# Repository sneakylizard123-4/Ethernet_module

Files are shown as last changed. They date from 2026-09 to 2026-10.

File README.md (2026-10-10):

# W5500 Ethernet Module

A small SPI Ethernet breakout for the W5500.

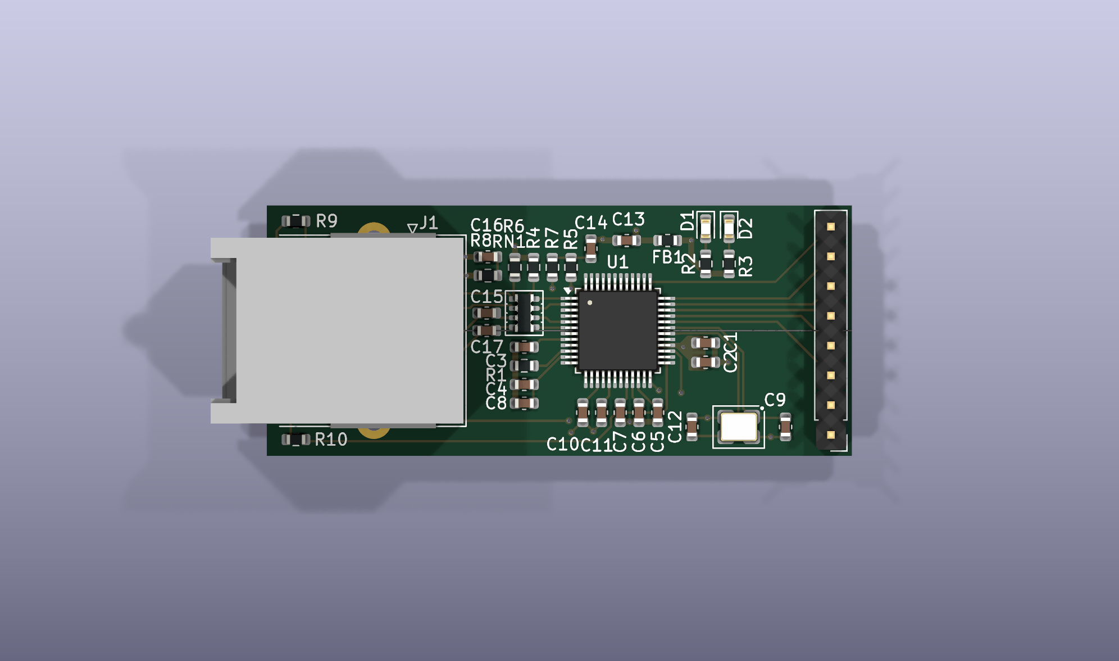
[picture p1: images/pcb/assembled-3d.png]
Assembled 3D render


## Features

- SPI interface
- 10/100 Ethernet
- 4-layer board with ground and 3.3V planes
- Split analog/digital supply with ferrite bead
- On-board and jack LEDs
- 25 MHz crystal

## PCB

50.0 x 21.4 mm, 4-layer, 1.6 mm FR-4.

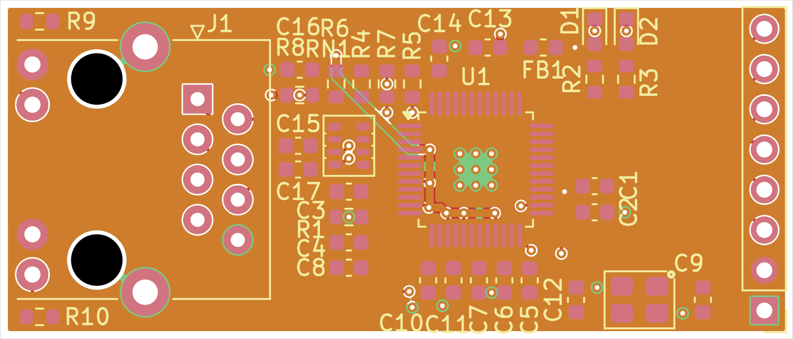
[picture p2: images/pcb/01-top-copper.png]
PCB top copper

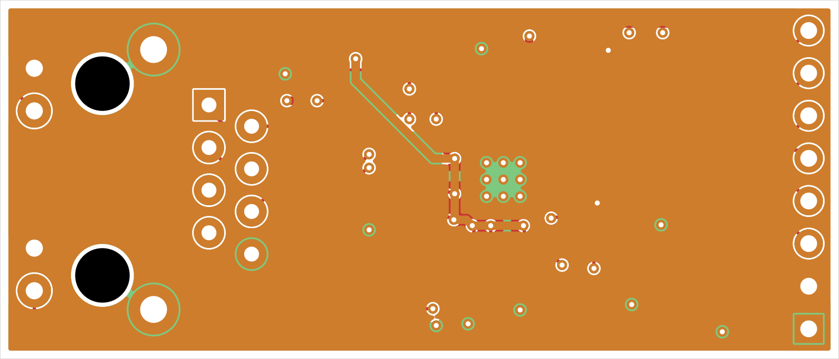
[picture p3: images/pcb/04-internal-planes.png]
Internal planes


## Schematic

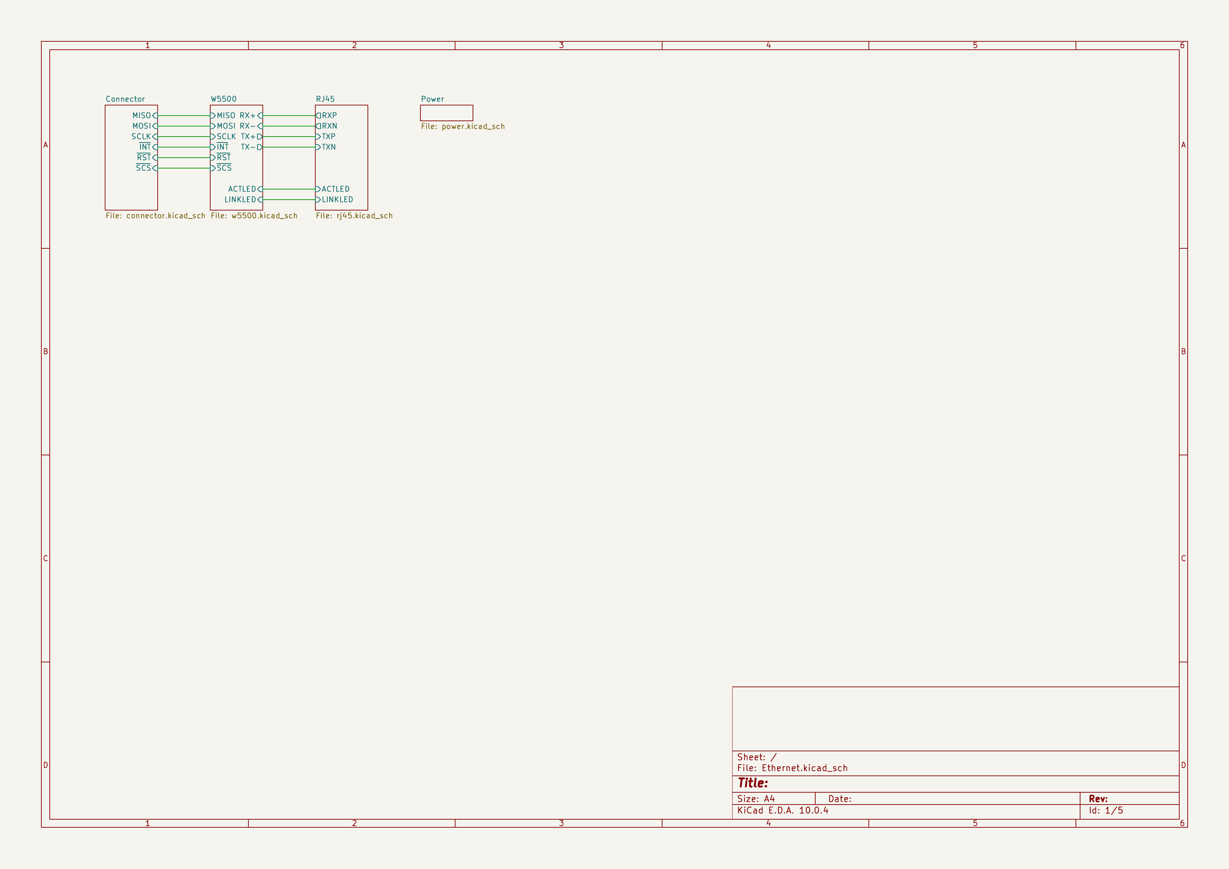
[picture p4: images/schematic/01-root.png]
Root

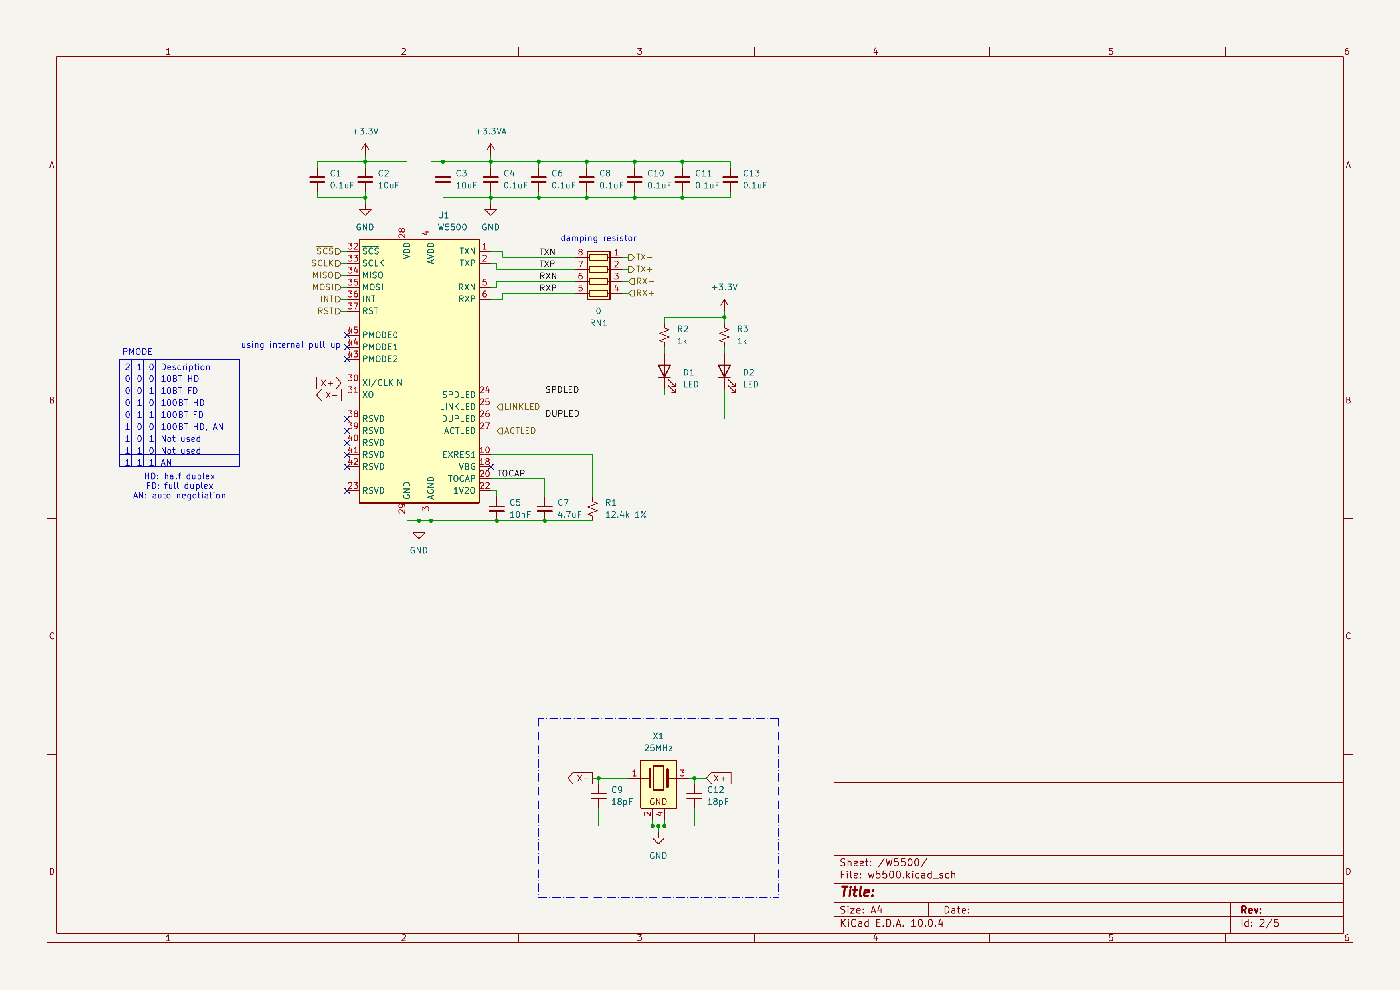
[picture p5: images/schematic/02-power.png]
Power

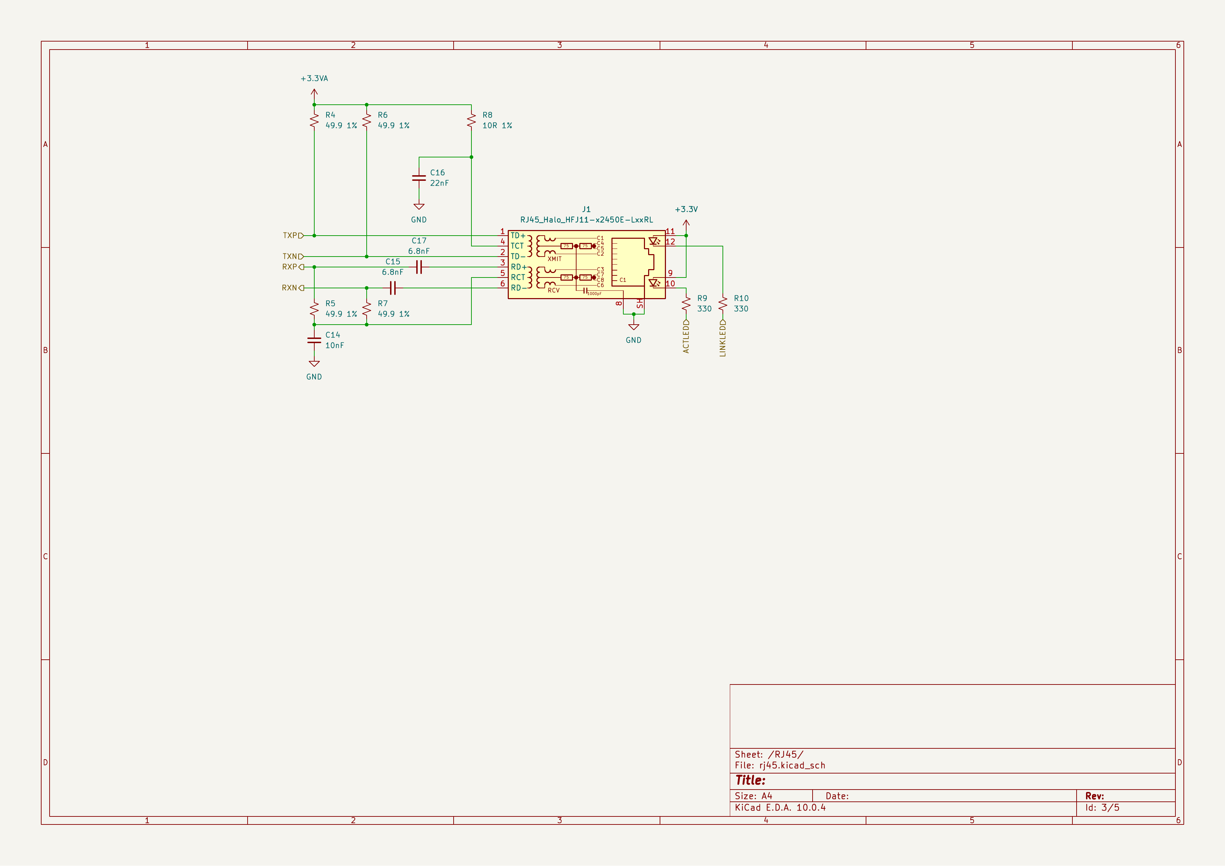
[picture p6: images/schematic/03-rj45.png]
RJ45

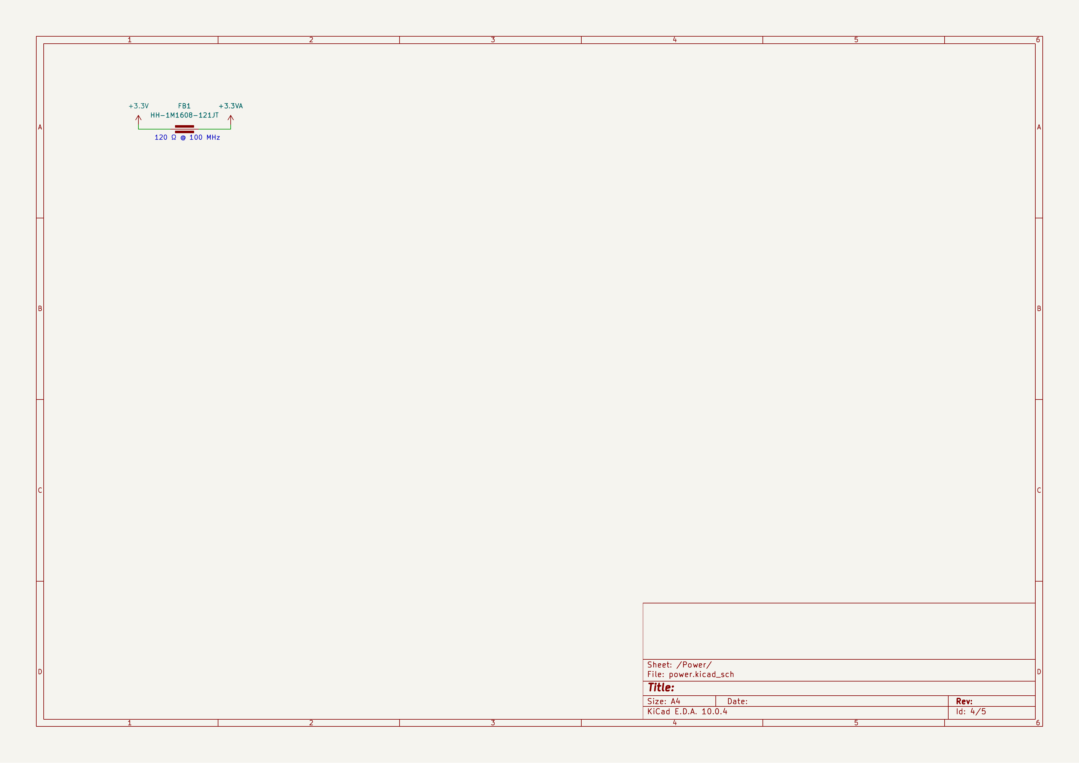
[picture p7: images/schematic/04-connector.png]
Connector

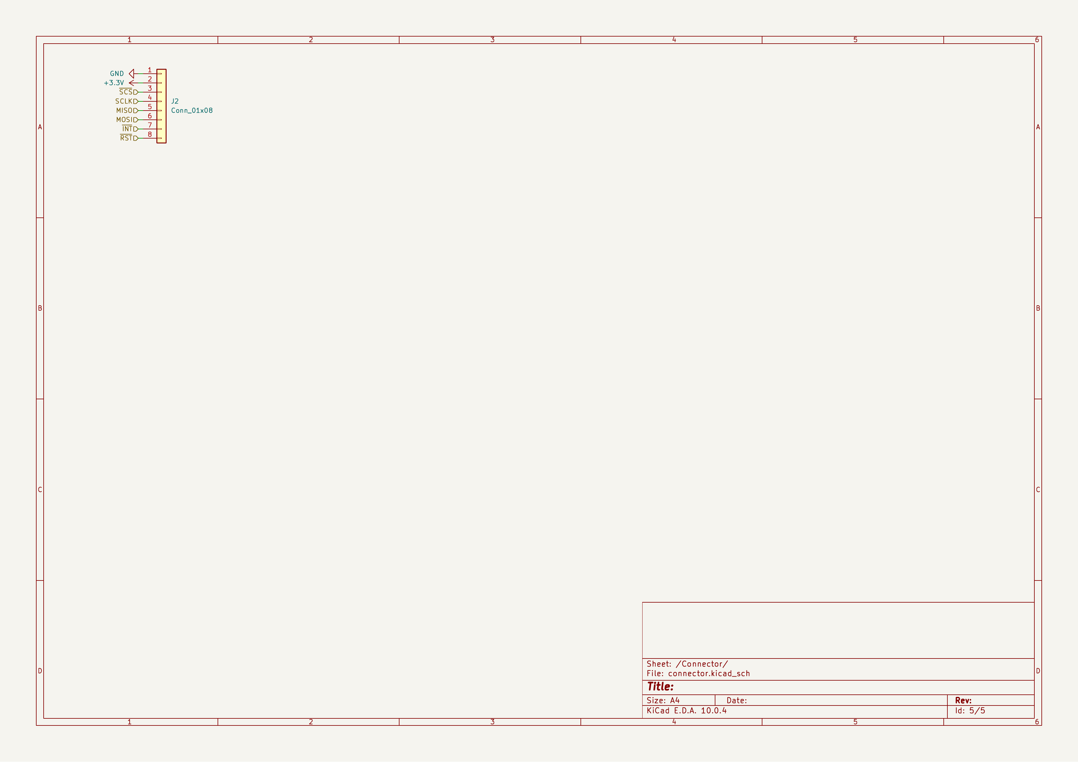
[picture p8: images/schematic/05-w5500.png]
W5500


## Pinout

| Pin | Name | Notes |
|---|---|---|
| 1 | GND | Ground |
| 2 | 3.3V | Power in |
| 3 | SCS | Chip select (active low) |
| 4 | SCLK | SPI clock |
| 5 | MISO | SPI MISO |
| 6 | MOSI | SPI MOSI |
| 7 | INT | Interrupt (active low) |
| 8 | RST | Reset (active low) |

## BOM

| Ref | Value | MPN | Manufacturer | Qty | Unit $ | Ext $ | Supplier Link |
|-----|---|-----|---|-----|---|---|---|
| C1,C4,C6,C8,C10,C11,C13 | 0.1uF 50V X7R 0603 | CL10B104KB8NNNC | Samsung Electro-Mechanics | 7 | 0.0088 | 0.0616 | [LCSC](https://www.lcsc.com/product-detail/Samsung-Electro-Mechanics-CL10B104KB8NNNC_C1591.html) |
| C9,C12 | 18pF 50V C0G 0603 | 0603N180J500CT | Union Semiconductor | 2 | 0.0069 | 0.0138 | [LCSC](https://www.lcsc.com/product-detail/Union-Semiconductor-0603N180J500CT_C123538.html) |
| C5,C14 | 10nF 50V X7R 0603 | CL10B103KB8NNNC | Samsung Electro-Mechanics | 2 | 0.0103 | 0.0206 | [LCSC](https://www.lcsc.com/product-detail/Samsung-Electro-Mechanics-CL10B103KB8NNNC_C1589.html) |
| C15,C17 | 6.8nF 50V X7R 0603 | CL10B682JB8NNNC | Samsung Electro-Mechanics | 2 | 0.0075 | 0.0150 | [LCSC](https://www.lcsc.com/product-detail/Samsung-Electro-Mechanics-CL10B682JB8NNNC_C307492.html) |
| C16 | 22nF 50V X7R 0603 | CC0603KRX7R9BB223 | Yageo | 1 | 0.0063 | 0.0063 | [LCSC](https://www.lcsc.com/product-detail/YAGEO-CC0603KRX7R9BB223_C106222.html) |
| C2,C3 | 10uF 10V X5R 0603 | CL10A106KP8NNNC | Samsung Electro-Mechanics | 2 | 0.0322 | 0.0644 | [LCSC](https://www.lcsc.com/product-detail/Samsung-Electro-Mechanics-CL10A106KP8NNNC_C19702.html) |
| C7 | 4.7uF 10V X5R 0603 | CL10A475KP8NNNC | Samsung Electro-Mechanics | 1 | 0.0164 | 0.0164 | [LCSC](https://www.lcsc.com/product-detail/Samsung-Electro-Mechanics-CL10A475KP8NNNC_C1705.html) |
| D1,D2 | LED red high-efficiency 0603 | KT-0603R | Keystone Electronics | 2 | 0.0076 | 0.0152 | [LCSC](https://www.lcsc.com/product-detail/Keystone-Electronics-KT-0603R_C2286.html) |
| FB1 | Ferrite bead 120R 0603 | CBW160808U121T | Sunlord | 1 | 0.0086 | 0.0086 | [LCSC](https://www.lcsc.com/product-detail/Sunlord-CBW160808U121T_C139175.html) |
| J1 | RJ45 magjack HFJ11-2450E-L11RL | HFJ11-2450E-L11RL | Halo Electronics | 1 | 5.2300 | 5.2300 | [DigiKey](https://www.digikey.com/en/products/detail/halo-electronics-inc/HFJ11-2450E-L11RL/25658121) |
| J2 | Header 1x08 2.54mm | 2.54-1*8 | CONNFLY Elec | 1 | 0.0442 | 0.0442 | [LCSC](https://www.lcsc.com/product-detail/CONNFLY-Elec-2-54-1-8_C5156616.html) |
| R1 | 12.4k 1% 0603 | 0603WAF1242T5E | UniRoyal Elec | 1 | 0.0015 | 0.0015 | [LCSC](https://www.lcsc.com/product-detail/UNI-ROYAL-Uniroyal-Elec-0603WAF1242T5E_C22865.html) |
| R2,R3 | 1k 1% 0603 | 0603WAF1001T5E | UniRoyal Elec | 2 | 0.0026 | 0.0052 | [LCSC](https://www.lcsc.com/product-detail/UNI-ROYAL-Uniroyal-Elec-0603WAF1001T5E_C21190.html) |
| R4,R5,R6,R7 | 49.9R 1% 0603 | RC0603FR-0749R9L | Yageo | 4 | 0.0062 | 0.0248 | [LCSC](https://www.lcsc.com/product-detail/YAGEO-RC0603FR-0749R9L_C114625.html) |
| R8 | 10R 1% 0603 | 0603WAF100JT5E | UniRoyal Elec | 1 | 0.0032 | 0.0032 | [LCSC](https://www.lcsc.com/product-detail/UNI-ROYAL-Uniroyal-Elec-0603WAF100JT5E_C22859.html) |
| R9,R10 | 330R 1% 0603 | 0603WAF3300T5E | UniRoyal Elec | 2 | 0.0026 | 0.0052 | [LCSC](https://www.lcsc.com/product-detail/UNI-ROYAL-Uniroyal-Elec-0603WAF3300T5E_C23138.html) |
| RN1 | 0R array 0603x4 | 4D03WGJ0000T5E | UniRoyal Elec | 1 | 0.0090 | 0.0090 | [LCSC](https://www.lcsc.com/product-detail/UNI-ROYAL-Uniroyal-Elec-4D03WGJ0000T5E_C1952.html) |
| U1 | W5500 LQFP-48 | W5500 | WIZnet | 1 | 2.8503 | 2.8503 | [LCSC](https://www.lcsc.com/product-detail/WIZnet-W5500_C32843.html) |
| X1 | 25MHz 3225 | TXC-7A-25.000MBB-T | TXC Corporation | 1 | 0.0954 | 0.0954 | [LCSC](https://www.lcsc.com/product-detail/TXC-Corp-TXC-7A-25-000MBB-T_C9006.html) |
| PCB | 50.0x21.4mm 4-layer FR-4 (5 pcs, est.) | - | JLCPCB | 5 | 2.0000 | 10.0000 | [JLCPCB](https://jlcpcb.com/) |
| **Total (parts per 1 board)** | | | | | | **8.49** | |
| **Grand total (5 boards: parts + PCBs)** | | | | | | **52.45** | |

Full BOM: [BOM.csv](BOM.csv)

## Production

Gerbers, drill files, STEP, IPC netlists, and placement files are in `kicad/production/`.

## Known issues

- The RJ45 mating face is ~6.1 mm closer to the board center than Halo recommends. Check case clearances.
- No mounting holes.

## License

Hardware: CERN-OHL-S-2.0. This covers the board design and the reconstructed 3D model for the magjack.

Based on WIZnet's W5500 reference design.

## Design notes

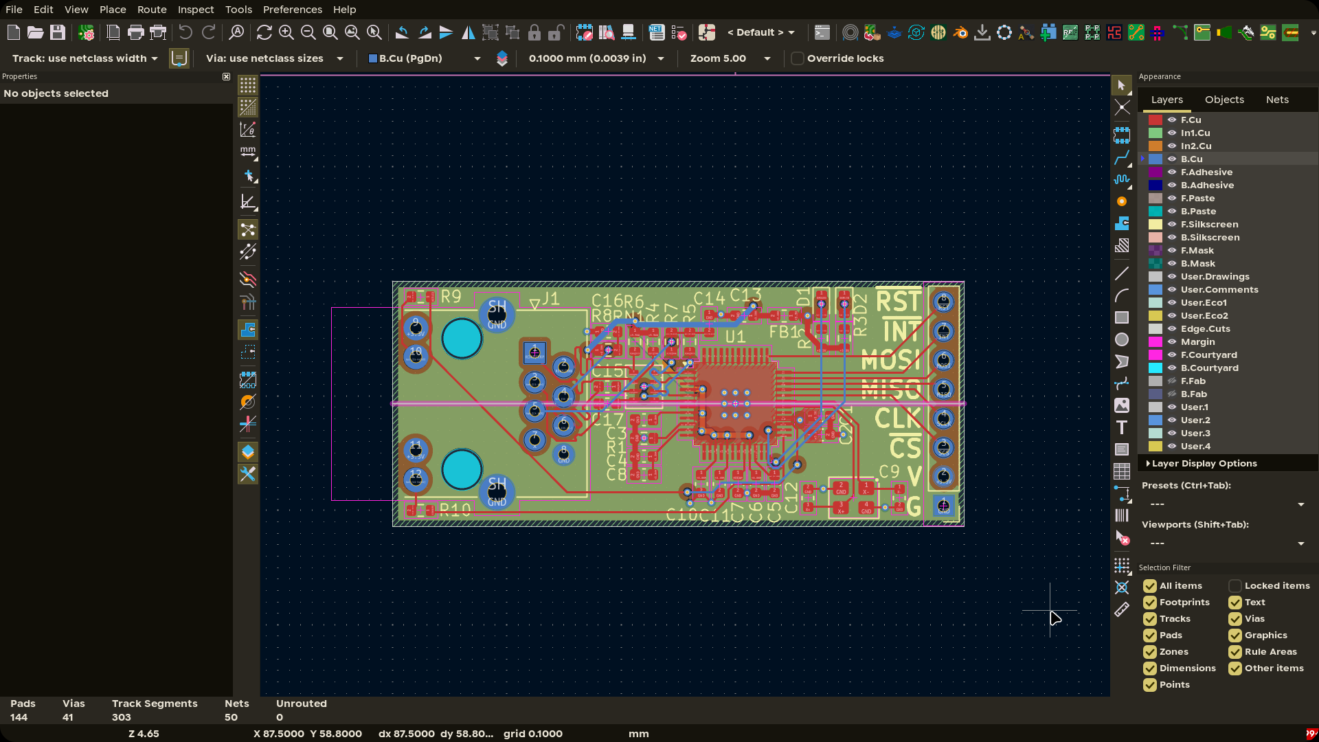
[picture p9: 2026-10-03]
images/pcb/image.png

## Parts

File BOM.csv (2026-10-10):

Designators | Value | Manufacturer Part Number | Manufacturer | Supplier | Supplier Link | Qty | Unit Price (USD) | Extended Price (USD)
C1,C4,C6,C8,C10,C11,C13 | 0.1uF 50V X7R 0603 | CL10B104KB8NNNC | Samsung Electro-Mechanics | LCSC | https://www.lcsc.com/product-detail/Samsung-Electro-Mechanics-CL10B104KB8NNNC_C1591.html | 7 | 0.0088 | 0.0616
C9,C12 | 18pF 50V C0G 0603 | 0603N180J500CT | Union Semiconductor | LCSC | https://www.lcsc.com/product-detail/Union-Semiconductor-0603N180J500CT_C123538.html | 2 | 0.0069 | 0.0138
C5,C14 | 10nF 50V X7R 0603 | CL10B103KB8NNNC | Samsung Electro-Mechanics | LCSC | https://www.lcsc.com/product-detail/Samsung-Electro-Mechanics-CL10B103KB8NNNC_C1589.html | 2 | 0.0103 | 0.0206
C15,C17 | 6.8nF 50V X7R 0603 | CL10B682JB8NNNC | Samsung Electro-Mechanics | LCSC | https://www.lcsc.com/product-detail/Samsung-Electro-Mechanics-CL10B682JB8NNNC_C307492.html | 2 | 0.0075 | 0.0150
C16 | 22nF 50V X7R 0603 | CC0603KRX7R9BB223 | Yageo | LCSC | https://www.lcsc.com/product-detail/YAGEO-CC0603KRX7R9BB223_C106222.html | 1 | 0.0063 | 0.0063
C2,C3 | 10uF 10V X5R 0603 | CL10A106KP8NNNC | Samsung Electro-Mechanics | LCSC | https://www.lcsc.com/product-detail/Samsung-Electro-Mechanics-CL10A106KP8NNNC_C19702.html | 2 | 0.0322 | 0.0644
C7 | 4.7uF 10V X5R 0603 | CL10A475KP8NNNC | Samsung Electro-Mechanics | LCSC | https://www.lcsc.com/product-detail/Samsung-Electro-Mechanics-CL10A475KP8NNNC_C1705.html | 1 | 0.0164 | 0.0164
D1,D2 | LED red high-efficiency 0603 | KT-0603R | Keystone Electronics | LCSC | https://www.lcsc.com/product-detail/Keystone-Electronics-KT-0603R_C2286.html | 2 | 0.0076 | 0.0152
FB1 | Ferrite bead 120R at 100MHz 0603 | CBW160808U121T | Sunlord | LCSC | https://www.lcsc.com/product-detail/Sunlord-CBW160808U121T_C139175.html | 1 | 0.0086 | 0.0086
J1 | RJ45 magjack 10/100 Base-T tab-down green/green LED | HFJ11-2450E-L11RL | Halo Electronics | DigiKey | https://www.digikey.com/en/products/detail/halo-electronics-inc/HFJ11-2450E-L11RL/25658121 | 1 | 5.2300 | 5.2300
J2 | Header 1x08 2.54mm vertical through-hole | 2.54-1*8 | CONNFLY Elec | LCSC | https://www.lcsc.com/product-detail/CONNFLY-Elec-2-54-1-8_C5156616.html | 1 | 0.0442 | 0.0442
R1 | 12.4k 1% 0603 | 0603WAF1242T5E | UniRoyal Elec | LCSC | https://www.lcsc.com/product-detail/UNI-ROYAL-Uniroyal-Elec-0603WAF1242T5E_C22865.html | 1 | 0.0015 | 0.0015
R2,R3 | 1k 1% 0603 | 0603WAF1001T5E | UniRoyal Elec | LCSC | https://www.lcsc.com/product-detail/UNI-ROYAL-Uniroyal-Elec-0603WAF1001T5E_C21190.html | 2 | 0.0026 | 0.0052
R4,R5,R6,R7 | 49.9R 1% 0603 | RC0603FR-0749R9L | Yageo | LCSC | https://www.lcsc.com/product-detail/YAGEO-RC0603FR-0749R9L_C114625.html | 4 | 0.0062 | 0.0248
R8 | 10R 1% 0603 | 0603WAF100JT5E | UniRoyal Elec | LCSC | https://www.lcsc.com/product-detail/UNI-ROYAL-Uniroyal-Elec-0603WAF100JT5E_C22859.html | 1 | 0.0032 | 0.0032
R9,R10 | 330R 1% 0603 | 0603WAF3300T5E | UniRoyal Elec | LCSC | https://www.lcsc.com/product-detail/UNI-ROYAL-Uniroyal-Elec-0603WAF3300T5E_C23138.html | 2 | 0.0026 | 0.0052
RN1 | 0R jumper array 4 elements 0603x4 convex | 4D03WGJ0000T5E | UniRoyal Elec | LCSC | https://www.lcsc.com/product-detail/UNI-ROYAL-Uniroyal-Elec-4D03WGJ0000T5E_C1952.html | 1 | 0.0090 | 0.0090
U1 | W5500 10/100 Ethernet SPI controller LQFP-48 7x7mm | W5500 | WIZnet | LCSC | https://www.lcsc.com/product-detail/WIZnet-W5500_C32843.html | 1 | 2.8503 | 2.8503
X1 | 25MHz crystal 12pF 3225-4P | TXC-7A-25.000MBB-T | TXC Corporation | LCSC | https://www.lcsc.com/product-detail/TXC-Corp-TXC-7A-25-000MBB-T_C9006.html | 1 | 0.0954 | 0.0954
PCB | 50.0mm x 21.4mm 4-layer FR-4 1.6mm HASL (5 pieces | estimated) | PCB | JLCPCB | JLCPCB | https://jlcpcb.com/ | 5 | 2.0000 | 10.0000
TOTAL per 1 board |  |  |  |  |  |  | 8.4907
TOTAL for 5 boards (parts only) |  |  |  |  |  |  | 42.4535
GRAND TOTAL (5 boards parts + 5 PCBs) |  |  |  |  |  |  | 52.4535

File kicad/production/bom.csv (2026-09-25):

Designator | Footprint | Quantity | Value | LCSC Part #
C1, C10, C11, C13, C4, C6, C8 | 0603 | 7 | 0.1uF
C12, C9 | 0603 | 2 | 18pF
C14, C5 | 0603 | 2 | 10nF
C15, C17 | 0603 | 2 | 6.8nF
C16 | 0603 | 1 | 22nF
C2, C3 | 0603 | 2 | 10uF
C7 | 0603 | 1 | 4.7uF
D1, D2 | 0603 | 2 | LED
FB1 | 0603 | 1 | HH-1M1608-121JT
J1 | RJ45_HALO_HFJ11-x2450E-LxxRL_Horizontal | 1 | RJ45_Halo_HFJ11-x2450E-LxxRL
J2 | PinHeader_1x08_P2.54mm_Vertical | 1 | Conn_01x08
R1 | 0603 | 1 | 12.4k 1%
R10, R9 | 0603 | 2 | 330
R2, R3 | 0603 | 2 | 1k
R4, R5, R6, R7 | 0603 | 4 | 49.9 1%
R8 | 0603 | 1 | 10R 1%
RN1 | R_Array_Convex_4x0603 | 1 | 0
U1 | LQFP-48_7x7mm_P0.5mm | 1 | W5500
X1 | Crystal_SMD_3225-4Pin_3.2x2.5mm | 1 | 25MHz

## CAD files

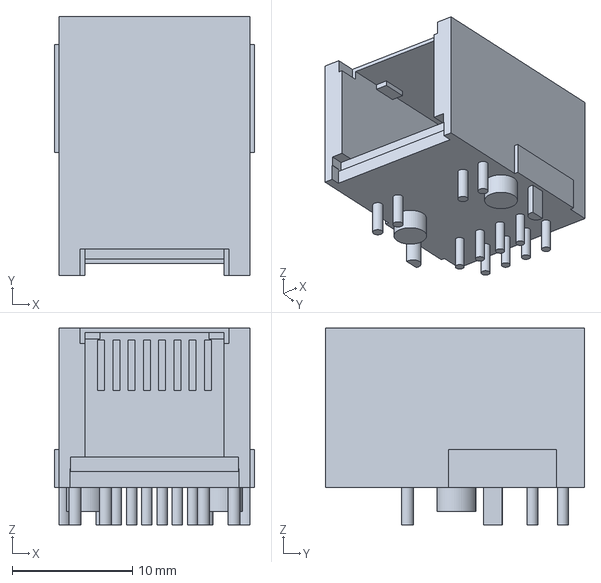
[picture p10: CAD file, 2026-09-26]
kicad/3dparts/halo_hfj11_x2450e_lxxrl.step
16.7 x 21.6 x 16.4 mm

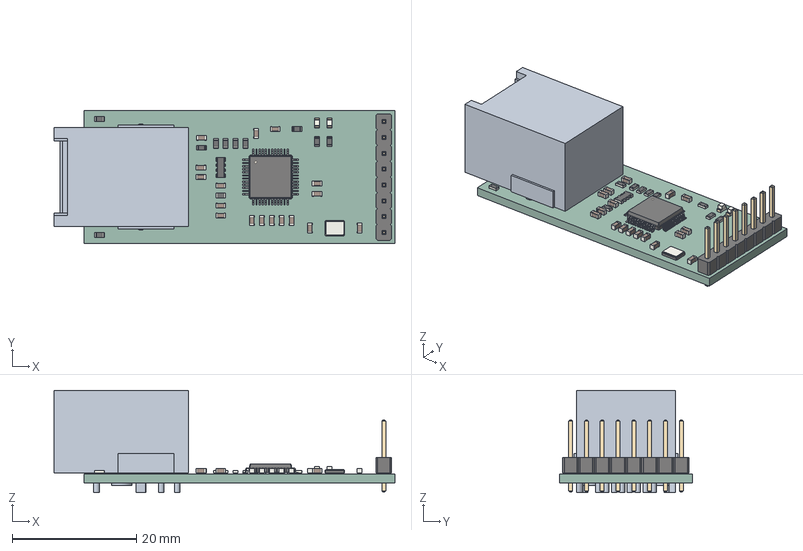
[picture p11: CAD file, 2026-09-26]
kicad/production/Ethernet.step
54.8 x 21.4 x 16.4 mm
C_0603_1608Metric x 17
R_0603_1608Metric x 10
R_Array_Convex_4x0603
LED_0603_1608Metric x 2
PinHeader_1x08_P254mm_Vertical
LQFP-48_7x7mm_P0.5mm
Fuse_0603_1608Metric
Crystal_SMD_3225-4Pin_3.2x2.5mm
Ethernet_PCB

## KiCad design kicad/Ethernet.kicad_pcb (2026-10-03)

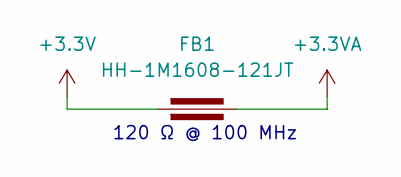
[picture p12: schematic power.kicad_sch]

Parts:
FB1: HH-1M1608-121JT; Fuse_0603_1608Metric

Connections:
+3.3V: FB1.1; also elsewhere on the board
+3.3VA: FB1.2; also elsewhere on the board

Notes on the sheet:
120 Ω @ 100 MHz

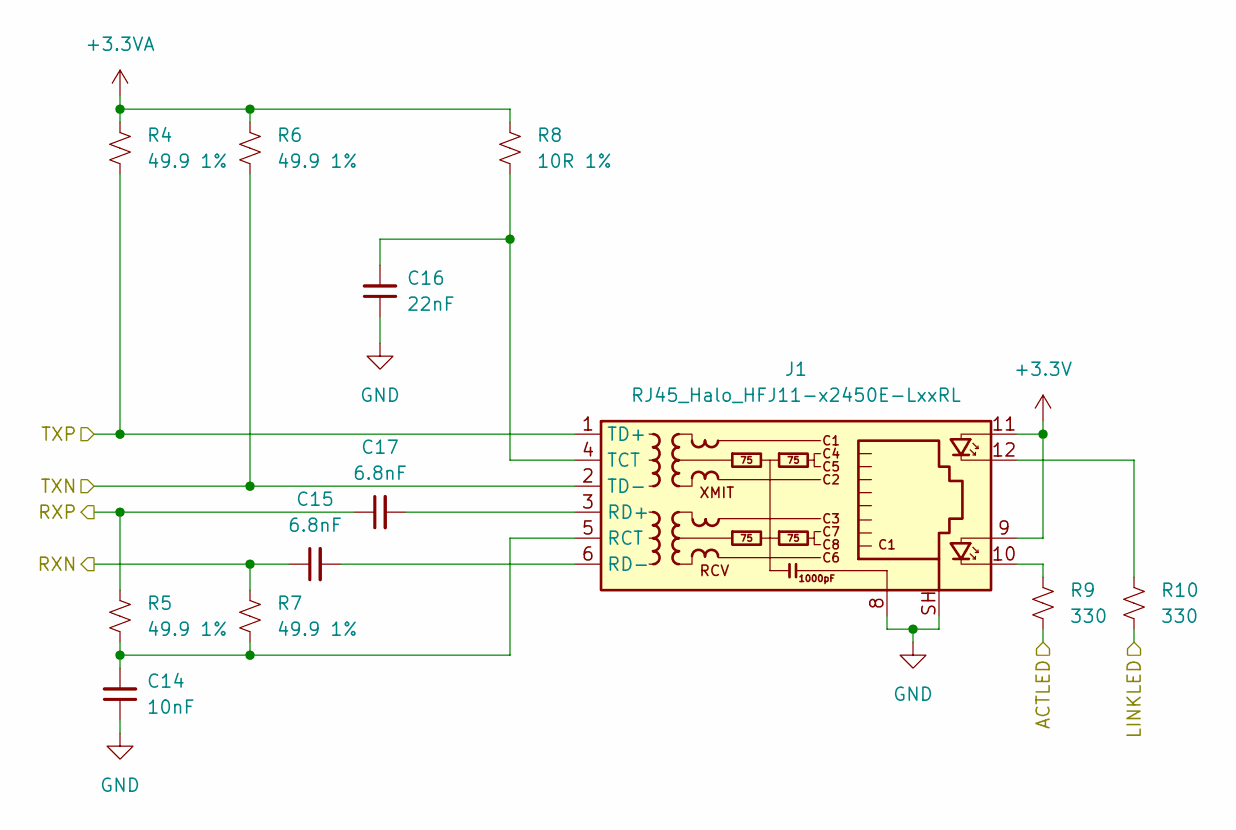
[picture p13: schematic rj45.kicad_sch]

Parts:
C14: 10nF; C_0603_1608Metric
C15, C17: 6.8nF; C_0603_1608Metric
C16: 22nF; C_0603_1608Metric
J1: RJ45_Halo_HFJ11-x2450E-LxxRL; RJ45_HALO_HFJ11-x2450E-LxxRL_Horizontal
R4, R5, R6, R7: 49.9 1%; R_0603_1608Metric
R8: 10R 1%; R_0603_1608Metric
R9, R10: 330; R_0603_1608Metric

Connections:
+3.3V: J1.9, J1.11; also elsewhere on the board
+3.3VA: R4.1, R6.1, R8.1; also elsewhere on the board
/RJ45/ACTLED: R9.1; also elsewhere on the board
/RJ45/LINKLED: R10.1; also elsewhere on the board
/RJ45/RXN: C15.1, R7.1; also elsewhere on the board
/RJ45/RXP: C17.1, R5.1; also elsewhere on the board
/RJ45/TXN: J1.2 (TD-), R6.2; also elsewhere on the board
/RJ45/TXP: J1.1 (TD+), R4.2; also elsewhere on the board
GND: C14.1, C16.1, J1.8, J1.SH; also elsewhere on the board
unnamed: J1.10, R9.2
unnamed: J1.12, R10.2
unnamed: C14.2, J1.5 (RCT), R5.2, R7.2
unnamed: C17.2, J1.3 (RD+)
unnamed: C15.2, J1.6 (RD-)
unnamed: C16.2, J1.4 (TCT), R8.2

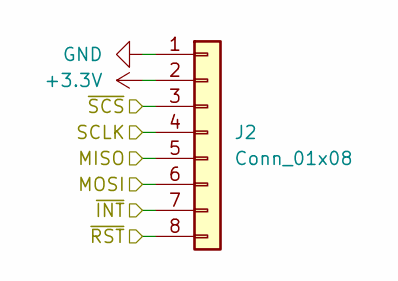
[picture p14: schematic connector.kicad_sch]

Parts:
J2: Conn_01x08; PinHeader_1x08_P2.54mm_Vertical

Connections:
+3.3V: J2.2; also elsewhere on the board
/Connector/MISO: J2.5; also elsewhere on the board
/Connector/MOSI: J2.6; also elsewhere on the board
/Connector/SCLK: J2.4; also elsewhere on the board
/Connector/~INT: J2.7; also elsewhere on the board
/Connector/~RST: J2.8; also elsewhere on the board
/Connector/~SCS: J2.3; also elsewhere on the board
GND: J2.1; also elsewhere on the board

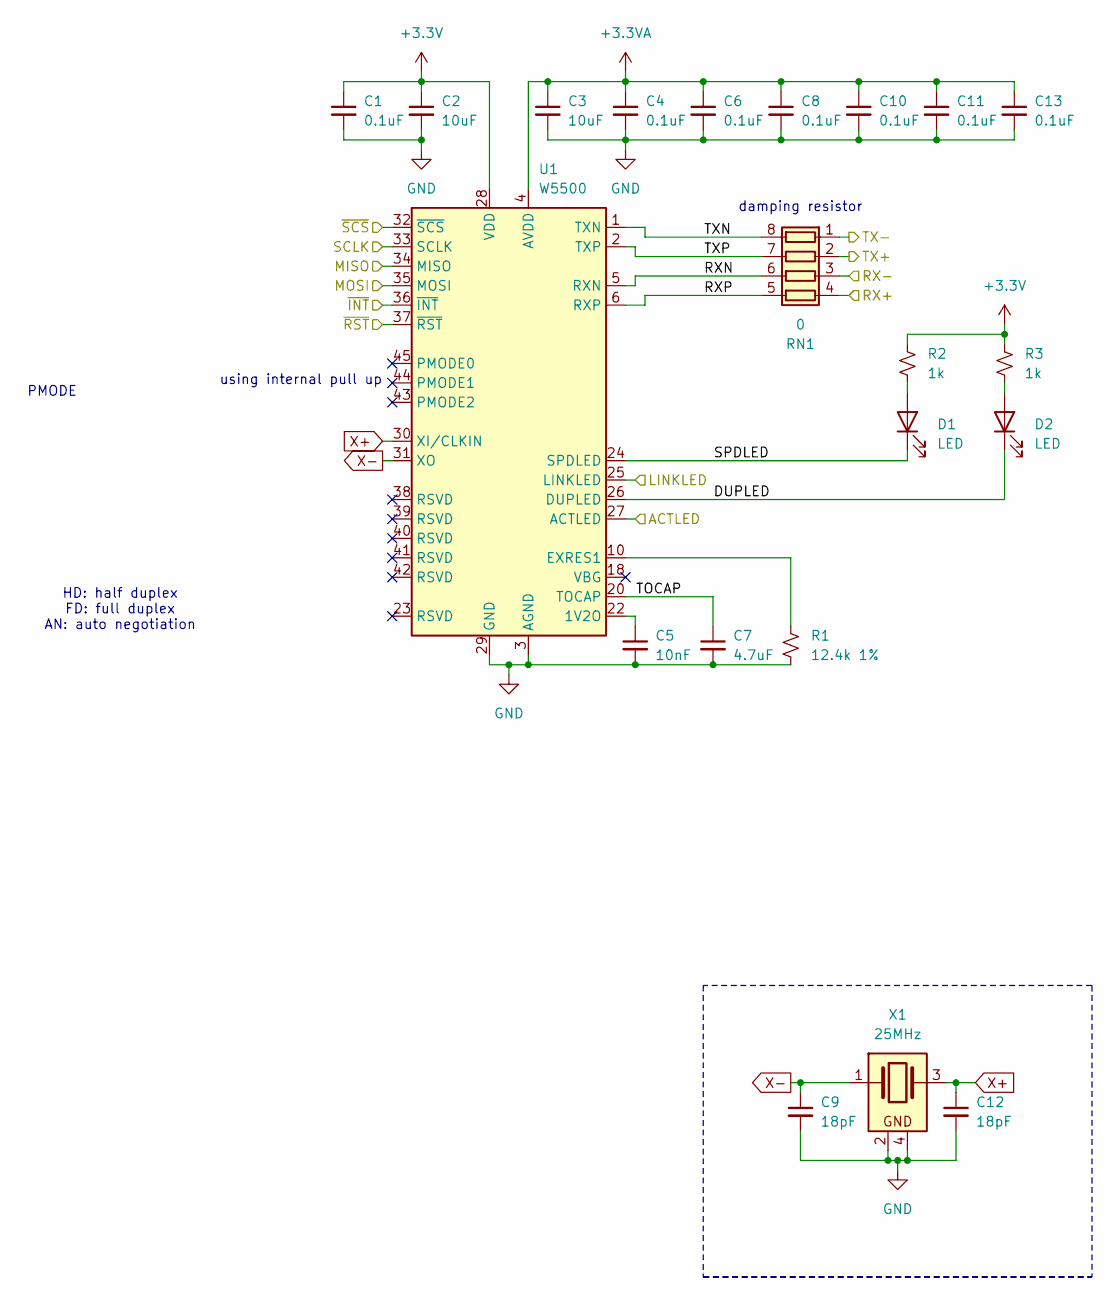
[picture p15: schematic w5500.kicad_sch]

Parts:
C1, C4, C6, C8, C10, C11, C13: 0.1uF; C_0603_1608Metric
C2, C3: 10uF; C_0603_1608Metric
C5: 10nF; C_0603_1608Metric
C7: 4.7uF; C_0603_1608Metric
C9, C12: 18pF; C_0603_1608Metric
D1, D2: LED; LED_0603_1608Metric
R1: 12.4k 1%; R_0603_1608Metric
R2, R3: 1k; R_0603_1608Metric
RN1: 0; R_Array_Convex_4x0603
U1: W5500; LQFP-48_7x7mm_P0.5mm
X1: 25MHz; Crystal_SMD_3225-4Pin_3.2x2.5mm

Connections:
+3.3V: C1.1, C2.1, R2.1, R3.1, U1.28 (VDD); also elsewhere on the board
+3.3VA: C3.1, C4.1, C6.1, C8.1, C10.1, C11.1, C13.1, U1.4 (AVDD), U1.8 (AVDD), U1.11 (AVDD), U1.15 (AVDD), U1.17 (AVDD), U1.21 (AVDD); also elsewhere on the board
/Connector/MISO: U1.34 (MISO); also elsewhere on the board
/Connector/MOSI: U1.35 (MOSI); also elsewhere on the board
/Connector/SCLK: U1.33 (SCLK); also elsewhere on the board
/Connector/~INT: U1.36 (~INT); also elsewhere on the board
/Connector/~RST: U1.37 (~RST); also elsewhere on the board
/Connector/~SCS: U1.32 (~SCS); also elsewhere on the board
/RJ45/ACTLED: U1.27 (ACTLED); also elsewhere on the board
/RJ45/LINKLED: U1.25 (LINKLED); also elsewhere on the board
/RJ45/RXN: RN1.3 (R3.1); also elsewhere on the board
/RJ45/RXP: RN1.4 (R4.1); also elsewhere on the board
/RJ45/TXN: RN1.1 (R1.1); also elsewhere on the board
/RJ45/TXP: RN1.2 (R2.1); also elsewhere on the board
/W5500/DUPLED: D2.1 (K), U1.26 (DUPLED)
/W5500/RXN: RN1.6 (R3.2), U1.5 (RXN)
/W5500/RXP: RN1.5 (R4.2), U1.6 (RXP)
/W5500/SPDLED: D1.1 (K), U1.24 (SPDLED)
/W5500/TOCAP: C7.1, U1.20 (TOCAP)
/W5500/TXN: RN1.8 (R1.2), U1.1 (TXN)
/W5500/TXP: RN1.7 (R2.2), U1.2 (TXP)
GND: C1.2, C2.2, C3.2, C4.2, C5.2, C6.2, C7.2, C8.2, C9.2, C10.2, C11.2, C12.2, C13.2, R1.2, U1.3 (AGND), U1.9 (AGND), U1.14 (AGND), U1.16 (AGND), U1.19 (AGND), U1.29 (GND), U1.48 (AGND), X1.2, X1.4; also elsewhere on the board
unnamed: D1.2 (A), R2.2
unnamed: D2.2 (A), R3.2
unnamed: C5.1, U1.22 (1V2O)
unnamed: R1.1, U1.10 (EXRES1)
X+: C12.1, U1.30 (XI/CLKIN), X1.3
X-: C9.1, U1.31 (XO), X1.1

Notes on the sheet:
PMODE
using internal pull up
damping resistor
HD: half duplex FD: full duplex AN: auto negotiation

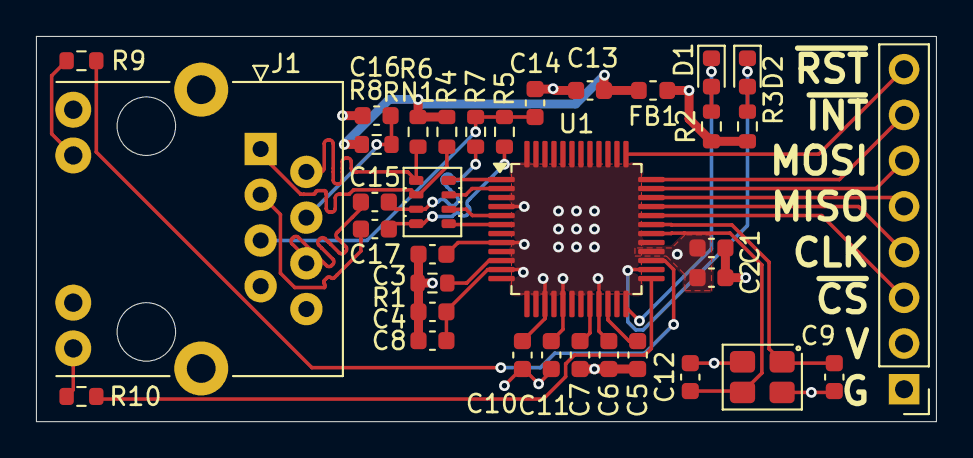
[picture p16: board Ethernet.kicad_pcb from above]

Board: 4 copper layers, 50.0 x 21.4 mm, 35 parts (0 on the bottom side), 34 nets.

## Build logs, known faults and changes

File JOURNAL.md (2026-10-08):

---
title: W5500 Ethernet Module
author: sneak
description: SPI Ethernet breakout built around the WIZnet W5500 and a Halo HFJ11 FastJack magjack.
created_at: 2026-09-25
---

# September 18: Schematic

## What I did:
- Drew the schematic
- Followed WIZnet's reference design
- Used 12.4k for EXRES1, 25MHz crystal with 18pF load caps
- Split into functional sheets

## Why:
- Wanted a safe reference for the magjack side
- Easier to keep track of power and signals

## Screenshots:
Root sheet

Power sheet

**Total time spent: 4 hours**

# September 20: Layout

## What I did:
- 50.0 x 21.4mm, 4 layers (GND on In1.Cu, 3.3V on In2.Cu)
- Routed Ethernet pairs on top with ground underneath
- Kept traces short and parallel

## Why:
- Easier to get clean routing than 2-layer for this board
- Wanted to know exactly what I routed

## Screenshots:
Top copper

**Total time spent: 7 hours**

# September 22: 3D model

## What I did:
- Built a STEP model for the Halo HFJ11 since none existed
- Calibrated from the mechanical drawing
- Generated VRML fallback

## Why:
- Needed for assembly check and README render
- Had to be explicit about guesses

## Screenshots:
Assembled 3D render

**Total time spent: 5 hours**

# September 24: Connector position fix

## What I did:
- Realized the mating face needs to be ~10.9mm from board edge
- Currently ~4.8mm - needs moving
- Documented the issue

## Why:
- Caught it while making the model
- Better to note it than ignore it

## Screenshots:
RJ45 sheet

**Total time spent: 2 hours**

# September 25: BOM, docs, production

## What I did:
- Sourced parts (magjack from DigiKey, rest mostly LCSC)
- Wrote README and journal
- Exported gerbers, drill, STEP
- Fixed .gitignore and cleaned up
- Rechecked DRC and fixed errors in README

## Why:
- Magjack drives most of the cost
- Wanted accurate docs

## Screenshots:
Assembled 3D render

**Total time spent: 4 hours**
